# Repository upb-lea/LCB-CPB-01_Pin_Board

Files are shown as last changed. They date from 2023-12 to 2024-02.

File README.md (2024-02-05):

# Pin board LCB-CPB-01 for the LEA control board

This is the pin board extension board for the LEA control board LCB-CCB-01. Please refer to the [LCB-CCB-01 repository](https://github.com/upb-lea/LCB-CCB-01_LEA_Control_Board) for a PCB and project overview.

Note, that you also need to install the `LEA KiCad Library` to view this PCB in this repository. To do this, follow the instructions mentioned [here](https://github.com/upb-lea/LCB-CCB-01_LEA_Control_Board/blob/main/README.md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).

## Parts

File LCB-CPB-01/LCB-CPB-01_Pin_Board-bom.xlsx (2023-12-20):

Prj: | LCB-CPB-01: Pin_Borad |  |  |  |  | Board Qty: | 100
Co.: | PADERBORN UNIVERSITY DEPARTMENT OF POWER ELECTRONICS AND ELECTRICAL DRIVES |  |  |  |  | Unit Cost: | €21.79
Prj date: | Mi 20 Dez 2023 11:09:16 CET |  |  |  |  | Total Cost: | €2179.30 |  |  |  |  | €2179.30 | 3 of 3 parts found
$ date: | 2023-12-20 11:20:31
Global Part Info |  |  |  |  |  |  |  | Mouser
Refs | Value | Footprint | Manf | Manf# | Qty | Unit$ | Ext$ | Avail | Purch | Unit$ | MOQ | Ext$ | Cat#
J1,J2 | ERM5-075-05.0-L-DV-K-TR | ERM5-075-05.0-L-DV | Samtec | ERM5-075-05.0-L-DV-K-TR (https://suddendocs.samtec.com/prints/erm5-xxx-xx.x-dv-xx-tr-footprint.pdf) | 200 | €7.660 | €1532.00 | 184 |  | €7.660 | 1 | €1532.00 | 200-ERM5075050LDVKTR (https://www.mouser.de/ProductDetail/Samtec/ERM5-075-05.0-L-DV-K-TR?qs=PB6%2FjmICvI31GHfBJZuD3w%3D%3D)
J3-J5 | 02x30_Row_Letter_Last | PinHeader_2x30_P2.54mm_Vertical | Amphenol | 77313-118-60LF (https://www.mouser.de/datasheet/2/18/1/bwb_bergstik-2584943.pdf) | 300 | €1.740 | €522.00 | 192 |  | €1.740 | 1 | €522.00 | 649-77313-118-60LF (https://eu.mouser.com/ProductDetail/Amphenol-FCI/77313-118-60LF?qs=xJiur%252Bgubk17gK0qL2Xi0A%3D%3D)
TP1-TP7 | TP_Keystone_Electronics_5019 | TestPoint_KeystoneElectronics5019 | Keystone Electronics | 5019 (https://www.keyelco.com/product.cfm/product_id/1357) | 700 | €0.179 | €125.30 | 231183 |  | €0.179 | 1 | €125.30 | 534-5019 (https://www.mouser.de/ProductDetail/Keystone-Electronics/5019?qs=wOxb8XianXjjCAsb90Ilzw%3D%3D)
 |  |  |  |  |  | Total Purchase: | €0.00 | Buy here (https://mouser.com/bom/) |  |  |  | €0.00
KiCost® v1.1.18 |  |  |  |  |  | Purchase description:

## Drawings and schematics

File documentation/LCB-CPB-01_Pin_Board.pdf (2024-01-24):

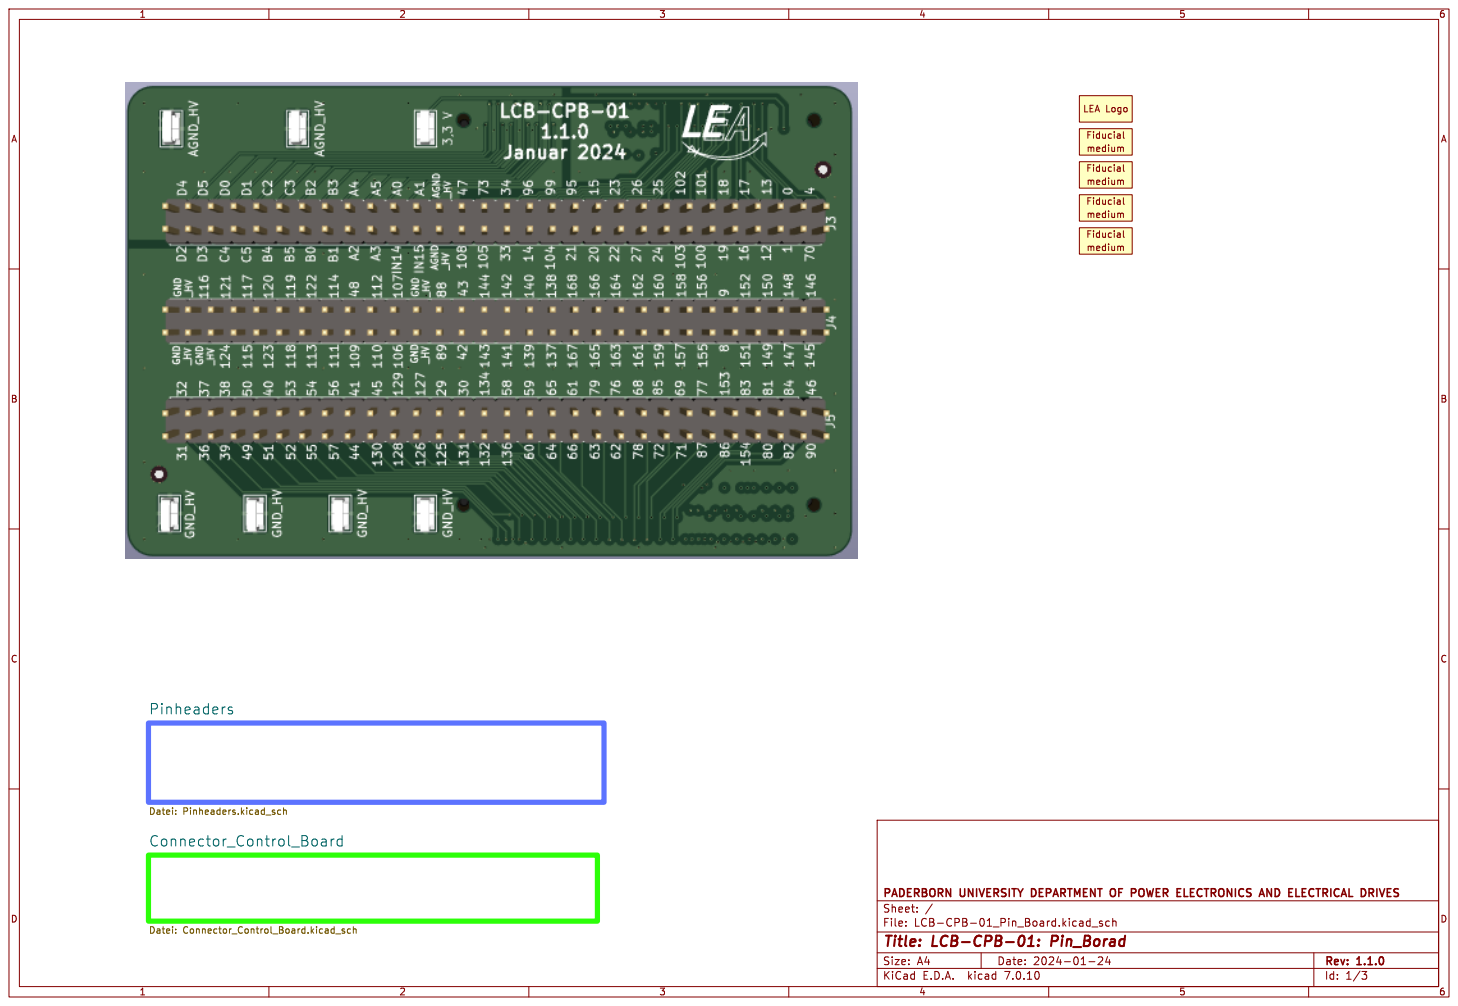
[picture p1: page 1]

LEA Logo Fiducial medium

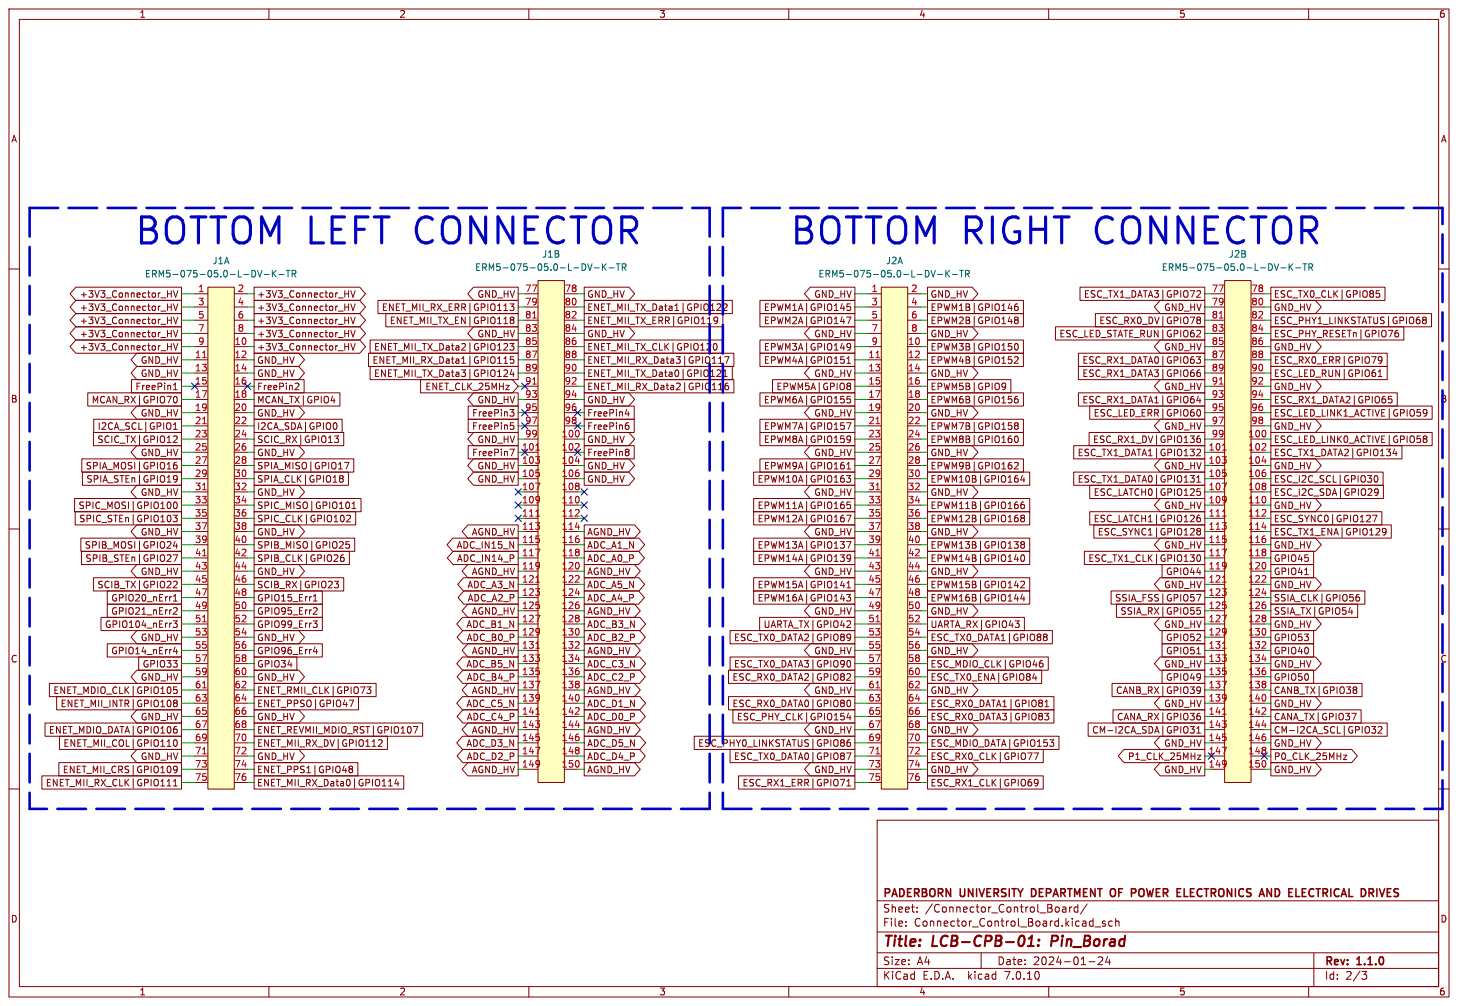
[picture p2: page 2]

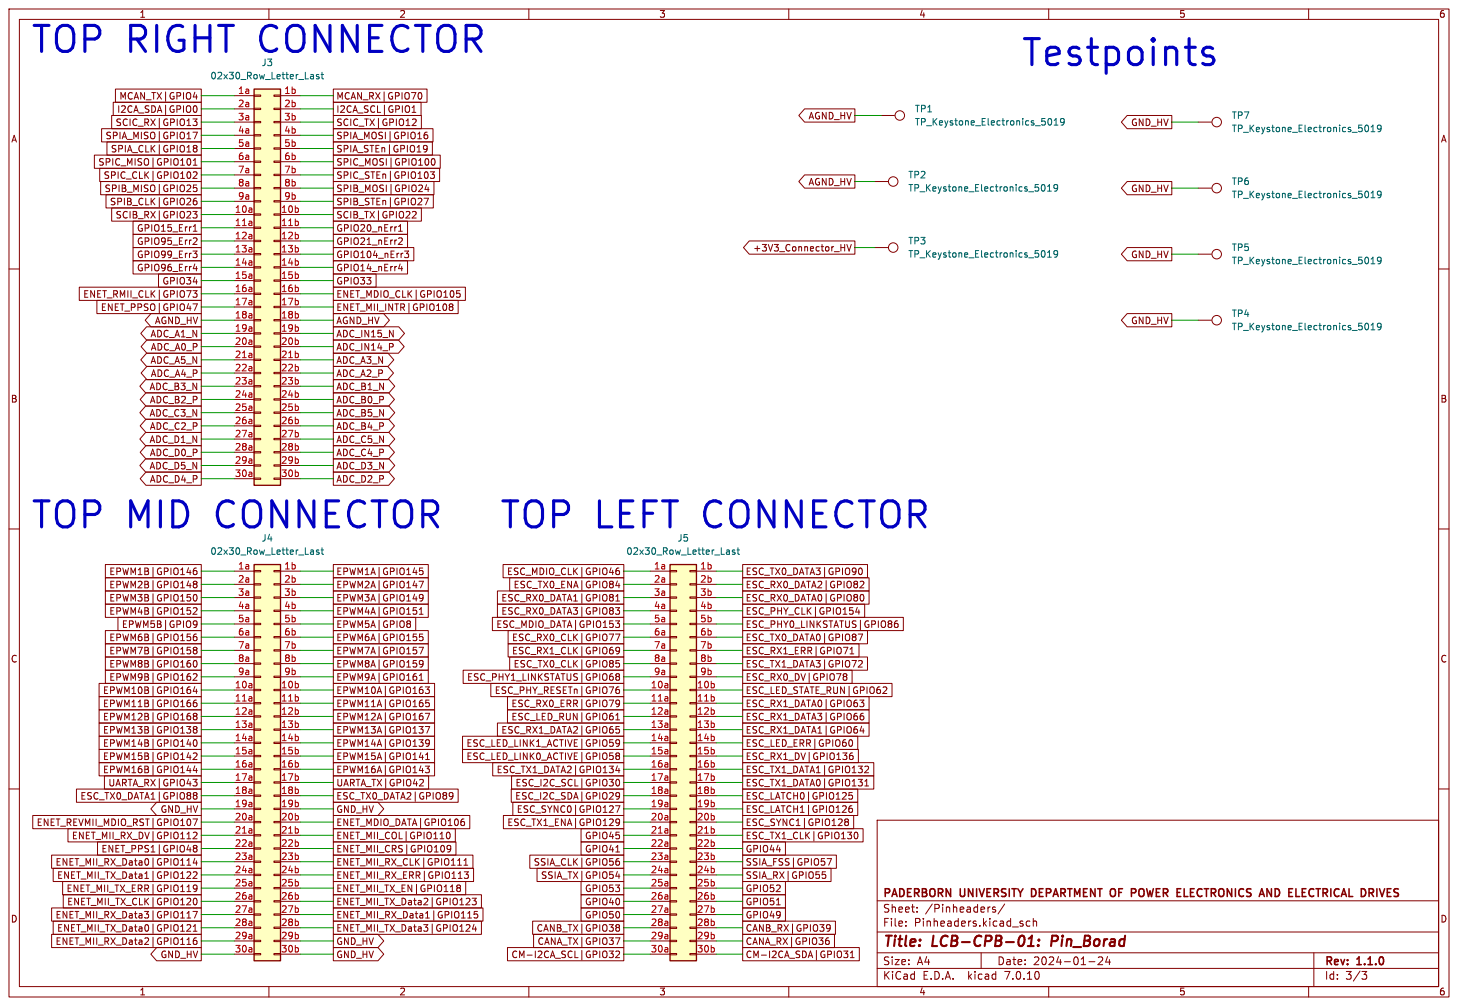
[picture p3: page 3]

ADC_C2_P
ADC_D1_N
TOP MID CONNECTOR TOP LEFT CONNECTOR

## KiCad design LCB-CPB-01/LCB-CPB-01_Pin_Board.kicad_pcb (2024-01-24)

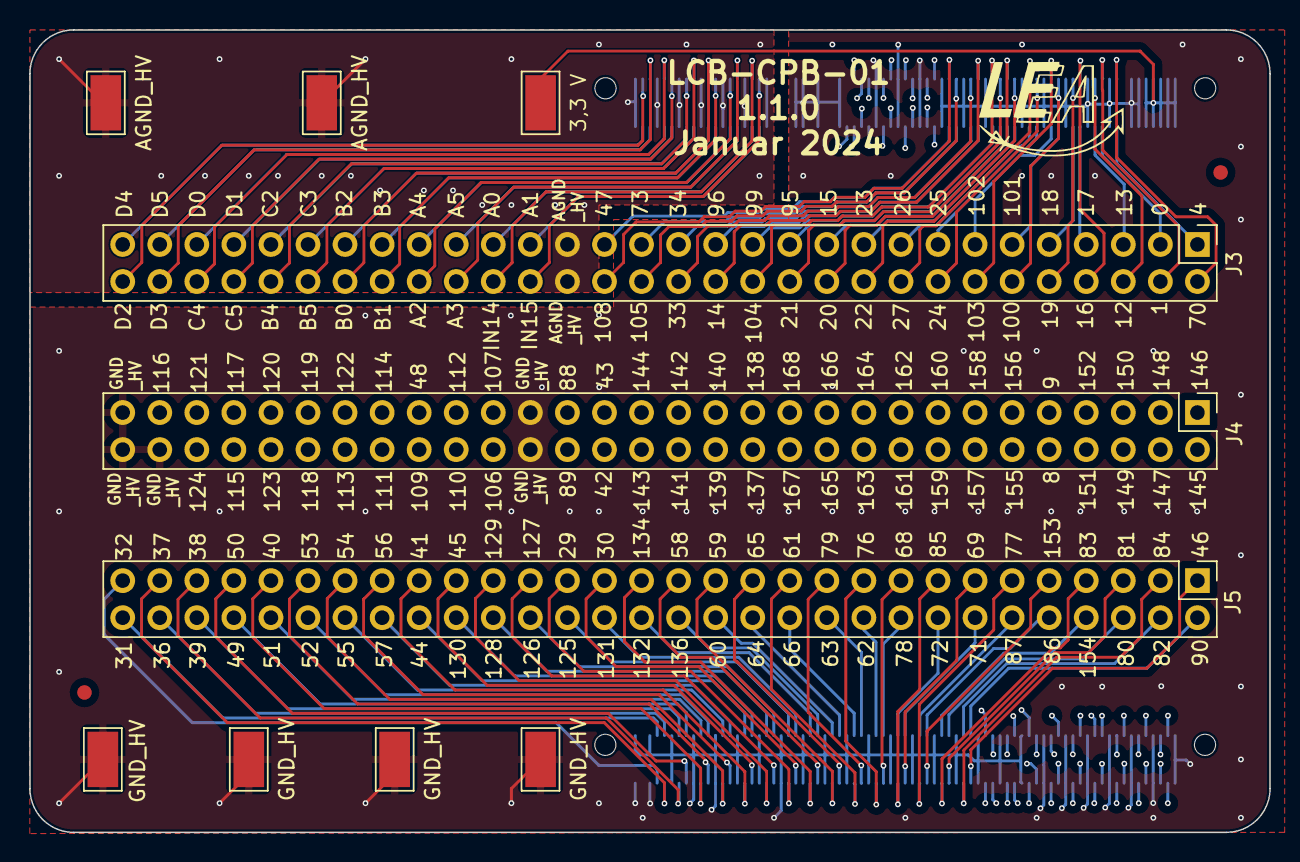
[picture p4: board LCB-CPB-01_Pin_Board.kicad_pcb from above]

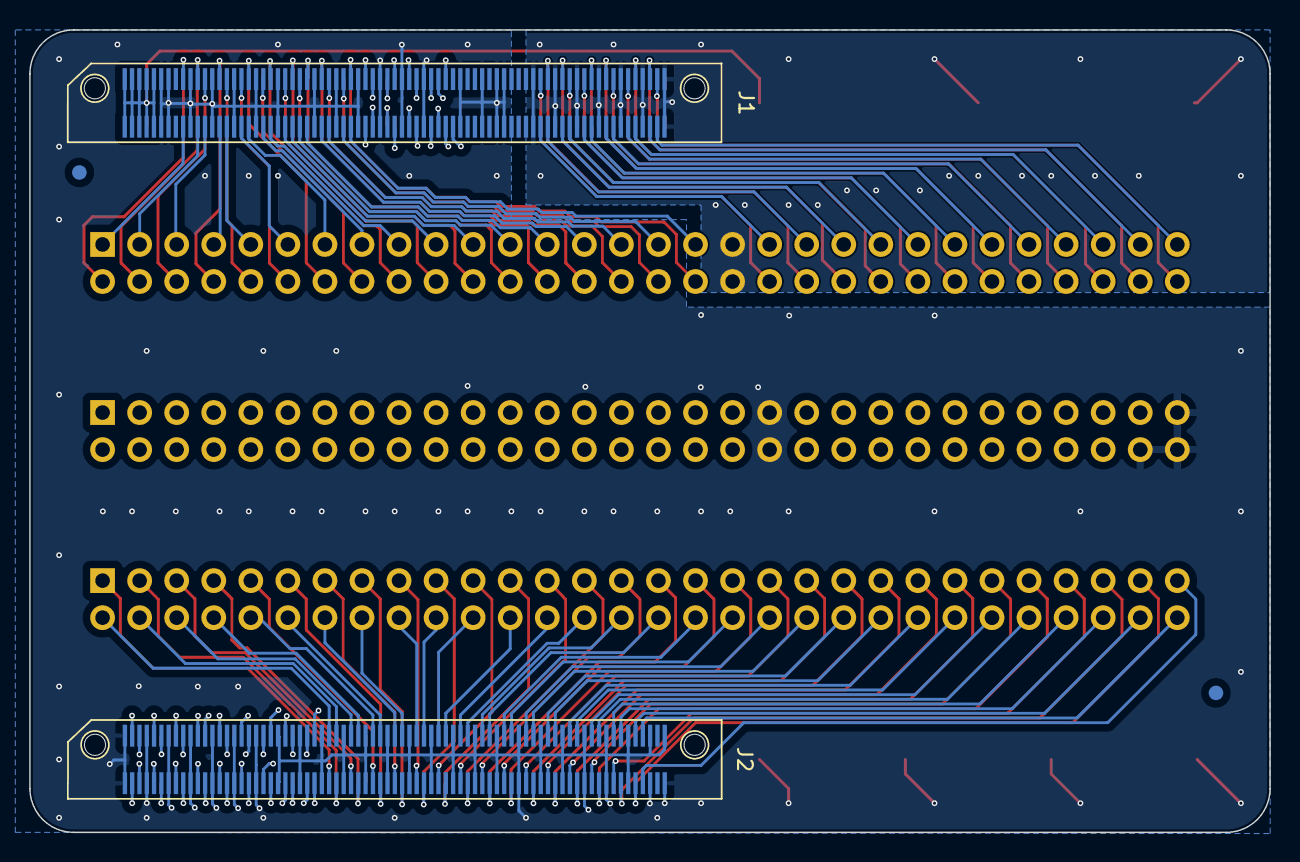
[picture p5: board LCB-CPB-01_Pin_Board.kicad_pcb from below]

Board: 4 copper layers, 85.0 x 55.0 mm, 17 parts (4 on the bottom side), 176 nets.

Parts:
3,3 V: TP_Keystone_Electronics_5019; TestPoint_KeystoneElectronics5019
AGND_HV: TP_Keystone_Electronics_5019; TestPoint_KeystoneElectronics5019
AGND_HV#2: TP_Keystone_Electronics_5019; TestPoint_KeystoneElectronics5019
GND_HV: TP_Keystone_Electronics_5019; TestPoint_KeystoneElectronics5019
GND_HV#2, GND_HV#3: TP_Keystone_Electronics_5019; TestPoint_KeystoneElectronics5019
J1, J2: ERM5-075-05.0-L-DV-K-TR; ERM5-075-05.0-L-DV
J3, J4, J5: 02x30_Row_Letter_Last; PinHeader_2x30_P2.54mm_Vertical
O1: SYM_LEA_Logo; SYM_lea_logo
O2, O3, O4, O5: Fiducial_medium; Fiducials_medium
TP7: TP_Keystone_Electronics_5019; TestPoint_KeystoneElectronics5019

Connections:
+3V3_Connector_HV: 3,3 V.1 (TP), J1.1, J1.2, J1.3, J1.4, J1.5, J1.6, J1.7, J1.8, J1.9, J1.10
ADC_A0_P: J1.118, J3.20a
ADC_A1_N: J1.116, J3.19a
ADC_A2_P: J1.123, J3.22b
ADC_A3_N: J1.121, J3.21b
ADC_A4_P: J1.124, J3.22a
ADC_A5_N: J1.122, J3.21a
ADC_B0_P: J1.129, J3.24b
ADC_B1_N: J1.127, J3.23b
ADC_B2_P: J1.130, J3.24a
ADC_B3_N: J1.128, J3.23a
ADC_B4_P: J1.135, J3.26b
ADC_B5_N: J1.133, J3.25b
ADC_C2_P: J1.136, J3.26a
ADC_C3_N: J1.134, J3.25a
ADC_C4_P: J1.141, J3.28b
ADC_C5_N: J1.139, J3.27b
ADC_D0_P: J1.142, J3.28a
ADC_D1_N: J1.140, J3.27a
ADC_D2_P: J1.147, J3.30b
ADC_D3_N: J1.145, J3.29b
ADC_D4_P: J1.148, J3.30a
ADC_D5_N: J1.146, J3.29a
ADC_IN14_P: J1.117, J3.20b
ADC_IN15_N: J1.115, J3.19b
AGND_HV: AGND_HV.1 (TP), AGND_HV#2.1 (TP), J1.113, J1.114, J1.119, J1.120, J1.125, J1.126, J1.131, J1.132, J1.137, J1.138, J1.143, J1.144, J1.149, J1.150, J3.18a, J3.18b
CANA_RX|GPIO36: J2.141, J5.29b
CANA_TX|GPIO37: J2.142, J5.29a
CANB_RX|GPIO39: J2.137, J5.28b
CANB_TX|GPIO38: J2.138, J5.28a
CM-I2CA_SCL|GPIO32: J2.144, J5.30a
CM-I2CA_SDA|GPIO31: J2.143, J5.30b
ENET_MDIO_CLK|GPIO105: J1.61, J3.16b
ENET_MDIO_DATA|GPIO106: J1.67, J4.20b
ENET_MII_COL|GPIO110: J1.69, J4.21b
ENET_MII_CRS|GPIO109: J1.73, J4.22b
ENET_MII_INTR|GPIO108: J1.63, J3.17b
ENET_MII_RX_CLK|GPIO111: J1.75, J4.23b
ENET_MII_RX_DV|GPIO112: J1.70, J4.21a
ENET_MII_RX_Data0|GPIO114: J1.76, J4.23a
ENET_MII_RX_Data1|GPIO115: J1.87, J4.27b
ENET_MII_RX_Data2|GPIO116: J1.92, J4.29a
ENET_MII_RX_Data3|GPIO117: J1.88, J4.27a
ENET_MII_RX_ERR|GPIO113: J1.79, J4.24b
ENET_MII_TX_CLK|GPIO120: J1.86, J4.26a
ENET_MII_TX_Data0|GPIO121: J1.90, J4.28a
ENET_MII_TX_Data1|GPIO122: J1.80, J4.24a
ENET_MII_TX_Data2|GPIO123: J1.85, J4.26b
ENET_MII_TX_Data3|GPIO124: J1.89, J4.28b
ENET_MII_TX_EN|GPIO118: J1.81, J4.25b
ENET_MII_TX_ERR|GPIO119: J1.82, J4.25a
ENET_PPS1|GPIO48: J1.74, J4.22a
ENET_PPSO|GPIO47: J1.64, J3.17a
ENET_REVMII_MDIO_RST|GPIO107: J1.68, J4.20a
ENET_RMII_CLK|GPIO73: J1.62, J3.16a
EPWM1A|GPIO145: J2.3, J4.1b
EPWM1B|GPIO146: J2.4, J4.1a
EPWM2A|GPIO147: J2.5, J4.2b
EPWM2B|GPIO148: J2.6, J4.2a
EPWM3A|GPIO149: J2.9, J4.3b
EPWM3B|GPIO150: J2.10, J4.3a
EPWM4A|GPIO151: J2.11, J4.4b
EPWM4B|GPIO152: J2.12, J4.4a
EPWM5A|GPIO8: J2.15, J4.5b
EPWM5B|GPIO9: J2.16, J4.5a
EPWM6A|GPIO155: J2.17, J4.6b
EPWM6B|GPIO156: J2.18, J4.6a
EPWM7A|GPIO157: J2.21, J4.7b
EPWM7B|GPIO158: J2.22, J4.7a
EPWM8A|GPIO159: J2.23, J4.8b
EPWM8B|GPIO160: J2.24, J4.8a
EPWM9A|GPIO161: J2.27, J4.9b
EPWM9B|GPIO162: J2.28, J4.9a
EPWM10A|GPIO163: J2.29, J4.10b
EPWM10B|GPIO164: J2.30, J4.10a
EPWM11A|GPIO165: J2.33, J4.11b
EPWM11B|GPIO166: J2.34, J4.11a
EPWM12A|GPIO167: J2.35, J4.12b
EPWM12B|GPIO168: J2.36, J4.12a
EPWM13A|GPIO137: J2.39, J4.13b
EPWM13B|GPIO138: J2.40, J4.13a
EPWM14A|GPIO139: J2.41, J4.14b
EPWM14B|GPIO140: J2.42, J4.14a
EPWM15A|GPIO141: J2.45, J4.15b
EPWM15B|GPIO142: J2.46, J4.15a
EPWM16A|GPIO143: J2.47, J4.16b
EPWM16B|GPIO144: J2.48, J4.16a
ESC_I2C_SCL|GPIO30: J2.106, J5.17a
ESC_I2C_SDA|GPIO29: J2.108, J5.18a
ESC_LATCH0|GPIO125: J2.107, J5.18b
ESC_LATCH1|GPIO126: J2.111, J5.19b
ESC_LED_ERR|GPIO60: J2.95, J5.14b
ESC_LED_LINK0_ACTIVE|GPIO58: J2.100, J5.15a
ESC_LED_LINK1_ACTIVE|GPIO59: J2.96, J5.14a
ESC_LED_RUN|GPIO61: J2.90, J5.12a
ESC_LED_STATE_RUN|GPIO62: J2.83, J5.10b
ESC_MDIO_CLK|GPIO46: J2.58, J5.1a
ESC_MDIO_DATA|GPIO153: J2.70, J5.5a
ESC_PHY0_LINKSTATUS|GPIO86: J2.69, J5.5b
ESC_PHY1_LINKSTATUS|GPIO68: J2.82, J5.9a
ESC_PHY_CLK|GPIO154: J2.65, J5.4b
ESC_PHY_RESETn|GPIO76: J2.84, J5.10a
ESC_RX0_CLK|GPIO77: J2.72, J5.6a
ESC_RX0_DATA0|GPIO80: J2.63, J5.3b
ESC_RX0_DATA1|GPIO81: J2.64, J5.3a
ESC_RX0_DATA2|GPIO82: J2.59, J5.2b
ESC_RX0_DATA3|GPIO83: J2.66, J5.4a
ESC_RX0_DV|GPIO78: J2.81, J5.9b
ESC_RX0_ERR|GPIO79: J2.88, J5.11a
ESC_RX1_CLK|GPIO69: J2.76, J5.7a
ESC_RX1_DATA0|GPIO63: J2.87, J5.11b
ESC_RX1_DATA1|GPIO64: J2.93, J5.13b
ESC_RX1_DATA2|GPIO65: J2.94, J5.13a
ESC_RX1_DATA3|GPIO66: J2.89, J5.12b
ESC_RX1_DV|GPIO136: J2.99, J5.15b
ESC_RX1_ERR|GPIO71: J2.75, J5.7b
ESC_SYNC0|GPIO127: J2.112, J5.19a
ESC_SYNC1|GPIO128: J2.113, J5.20b
ESC_TX0_CLK|GPIO85: J2.78, J5.8a
ESC_TX0_DATA0|GPIO87: J2.71, J5.6b
ESC_TX0_DATA1|GPIO88: J2.54, J4.18a
ESC_TX0_DATA2|GPIO89: J2.53, J4.18b
ESC_TX0_DATA3|GPIO90: J2.57, J5.1b
ESC_TX0_ENA|GPIO84: J2.60, J5.2a
ESC_TX1_CLK|GPIO130: J2.117, J5.21b
ESC_TX1_DATA0|GPIO131: J2.105, J5.17b
ESC_TX1_DATA1|GPIO132: J2.101, J5.16b
ESC_TX1_DATA2|GPIO134: J2.102, J5.16a
ESC_TX1_DATA3|GPIO72: J2.77, J5.8b
ESC_TX1_ENA|GPIO129: J2.114, J5.20a
GND_HV: GND_HV.1 (TP), GND_HV#2.1 (TP), GND_HV#3.1 (TP), J1.11, J1.12, J1.13, J1.14, J1.19, J1.20, J1.25, J1.26, J1.31, J1.32, J1.37, J1.38, J1.43, J1.44, J1.53, J1.54, J1.59, J1.60, J1.65, J1.66, J1.71, J1.72, J1.77, J1.78, J1.83, J1.84, J1.93, J1.94, J1.99, J1.100, J1.103, J1.104, J1.105, J1.106, J2.1, J2.2, J2.7, J2.8, J2.13, J2.14, J2.19, J2.20, J2.25, J2.26, J2.31, J2.32, J2.37, J2.38, J2.43, J2.44, J2.49, J2.50, J2.55, J2.56, J2.61, J2.62, J2.67, J2.68, J2.73, J2.74, J2.79, J2.80, J2.85, J2.86, J2.91, J2.92, J2.97, J2.98, J2.103, J2.104, J2.109, J2.110, J2.115, J2.116, J2.121, J2.122, J2.127, J2.128, J2.133, J2.134, J2.139, J2.140, J2.145, J2.146, J2.149, J2.150, J4.19a, J4.19b, J4.29b, J4.30a, J4.30b, TP7.1 (TP)
GPIO14_nErr4: J1.55, J3.14b
GPIO15_Err1: J1.48, J3.11a
GPIO20_nErr1: J1.47, J3.11b
GPIO21_nErr2: J1.49, J3.12b
GPIO33: J1.57, J3.15b
GPIO34: J1.58, J3.15a
GPIO40: J2.132, J5.26a
GPIO41: J2.120, J5.22a
GPIO44: J2.119, J5.22b
GPIO45: J2.118, J5.21a
GPIO49: J2.135, J5.27b
GPIO50: J2.136, J5.27a
GPIO51: J2.131, J5.26b
GPIO52: J2.129, J5.25b
GPIO53: J2.130, J5.25a
GPIO95_Err2: J1.50, J3.12a
GPIO96_Err4: J1.56, J3.14a
GPIO99_Err3: J1.52, J3.13a
GPIO104_nErr3: J1.51, J3.13b
I2CA_SCL|GPIO1: J1.21, J3.2b
I2CA_SDA|GPIO0: J1.22, J3.2a
MCAN_RX|GPIO70: J1.17, J3.1b
MCAN_TX|GPIO4: J1.18, J3.1a
SCIB_RX|GPIO23: J1.46, J3.10a
SCIB_TX|GPIO22: J1.45, J3.10b
SCIC_RX|GPIO13: J1.24, J3.3a
SCIC_TX|GPIO12: J1.23, J3.3b
SPIA_CLK|GPIO18: J1.30, J3.5a
SPIA_MISO|GPIO17: J1.28, J3.4a
SPIA_MOSI|GPIO16: J1.27, J3.4b
SPIA_STEn|GPIO19: J1.29, J3.5b
SPIB_CLK|GPIO26: J1.42, J3.9a
SPIB_MISO|GPIO25: J1.40, J3.8a
SPIB_MOSI|GPIO24: J1.39, J3.8b
SPIB_STEn|GPIO27: J1.41, J3.9b
SPIC_CLK|GPIO102: J1.36, J3.7a
SPIC_MISO|GPIO101: J1.34, J3.6a
SPIC_MOSI|GPIO100: J1.33, J3.6b
SPIC_STEn|GPIO103: J1.35, J3.7b
SSIA_CLK|GPIO56: J2.124, J5.23a
SSIA_FSS|GPIO57: J2.123, J5.23b
SSIA_RX|GPIO55: J2.125, J5.24b
SSIA_TX|GPIO54: J2.126, J5.24a
UARTA_RX|GPIO43: J2.52, J4.17a
UARTA_TX|GPIO42: J2.51, J4.17b

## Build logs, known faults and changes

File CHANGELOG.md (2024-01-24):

# Changelog

All notable changes to this project will be documented in this file.

The format is based on [Keep a Changelog](https://keepachangelog.com/en/1.0.0/),
and this project adheres to [Semantic Versioning](https://semver.org/spec/v2.0.0.html).

## [Unreleased]

## [1.1.0] - 2024-01-24
### Added
- Changelog file
### Fixed
- Fixed problem with the twisted plug.

## [1.0.0] - 2023-12-20
### Added
- Pin board for the LEA control board (LCB)
- Initial schematics and layout

[unreleased]: https://github.com/upb-lea/LCB-CPB-01_Pin_Board/compare/1.1.0...HEAD
[1.1.0]: https://github.com/upb-lea/LCB-CPB-01_Pin_Board/compare/1.0.0...1.1.0
[1.0.0]: https://github.com/upb-lea/LCB-CPB-01_Pin_Board/releases/tag/1.0.0

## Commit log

2023-12-13 Inital commit Pin_Borad
    [Connector_Control_Board.kicad_sch, LCB-CPB-01_Pin_Board.kicad_pcb, LCB-CPB-01_Pin_Board.kicad_sch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]
2023-12-13 First Review
    [LCB-CPB-01_Pin_Board.kicad_pcb, Pinheaders.kicad_sch]
2023-12-14 2nd Review
    [LCB-CPB-01_Pin_Board.kicad_pcb]
2023-12-14 2nd Review shift 3,3V Connection
    [LCB-CPB-01_Pin_Board.kicad_pcb]
2023-12-14 fix filepath for symbol and footprint library
2023-12-15 2nd Review Footprint update
    [LCB-CPB-01_Pin_Board.kicad_pcb, LCB-CPB-01_Pin_Board.kicad_sch, Pinheaders.kicad_sch]
2023-12-17 Change comment in scematic
    [Connector_Control_Board.kicad_sch, Pinheaders.kicad_sch]
2023-12-18 Update Silkscreen
    [LCB-CPB-01_Pin_Board.kicad_pcb]
2023-12-19 Separate GND into AGND_HV and GND_HV (+Silkscreen)
    [Connector_Control_Board.kicad_sch, LCB-CPB-01_Pin_Board.kicad_pcb, Pinheaders.kicad_sch]
2023-12-20 change probe connectors, fix warnings in schematic
    [Connector_Control_Board.kicad_sch, LCB-CPB-01_Pin_Board.kicad_pcb, LCB-CPB-01_Pin_Board.kicad_sch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]
2023-12-20 add pdf schematic and bom
    [LCB-CPB-01_Pin_Board-bom.xlsx, LCB-CPB-01_Pin_Board.kicad_sch]
2024-01-17 Changed Positions of conectors
    In the layout the conectors J1 and J2 had to be chaged.
    [LCB-CPB-01_Pin_Board_Changed_Positions.kicad_pcb, Pinheaders.kicad_sch]
2024-01-23 Routing for changed positions of connectors
    [LCB-CPB-01_Pin_Board.kicad_pcb, LCB-CPB-01_Pin_Board_Changed_Positions.kicad_pcb, Pinheaders.kicad_sch]
2024-01-24 bump schematic version to 1.1.0
    [Connector_Control_Board.kicad_sch, LCB-CPB-01_Pin_Board.kicad_sch, Pinheaders.kicad_sch]
2024-01-24 bump version to 1.1.0
    [LCB-CPB-01_Pin_Board.kicad_pcb, LCB-CPB-01_Pin_Board.kicad_sch]
